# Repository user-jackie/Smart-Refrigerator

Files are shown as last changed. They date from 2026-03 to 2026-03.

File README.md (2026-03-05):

# Smart-Refrigerator
A smart refrigerator based on rk3568

如果学习过相关内容的同学就会发现这个东西是基本没有技术难度的，那为什么要做这个东西呢，因为是学校的课，懂得都懂。虽然没有技术难度，但毕竟是本人第一个伪全栈项目(因为rk3568的高速板用的是开发板)，还是比较有纪念意义的。

说一下感想吧，现在ai的发展真是日新月异。如果让我从头写这些qt代码可能一个月都写不出来，但是现在用ai来写一个星期功能就大差不差，还是用的免费的Claude Code版本。个人感觉学习技术的成本越来越低，特别是和应用型代码相关的技术，也许以后使用一门技术只需要了解这门技术叫什么名字就行了？遵循规则是没有出路的，要么制定规则，要么打破规则。

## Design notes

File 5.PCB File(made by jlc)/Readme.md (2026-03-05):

# 嘉立创PCB文件

这里的pcb主要是两个扩展板，使用的开发板不一样的话pcb文件没有参考价值，不建议下载，这里给出思路。

1.因为做的是一个民用产品，所以首先得需要220v的电压输入转为直流输出，在淘宝上买一个220v转12v的变压器(转多少v直流自己决定)，转12v是因为提前买了12v的加热片和制冷片。

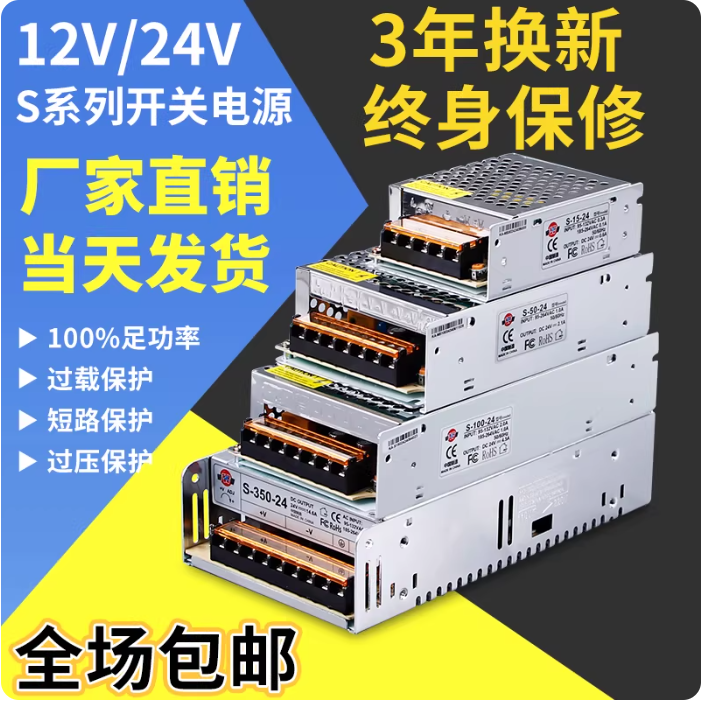
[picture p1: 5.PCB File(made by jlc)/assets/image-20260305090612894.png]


2.因为需要使用开发板上的gpio控制外部器件的通断，rk3568 gpio最高输出3.3v，所以需要一个能够3.3v控制12v电压通断的元件，作者选用的是3.3v电平触发的继电器(需要考虑到12v那边的最大电流，大功率制冷片需要的电流很大)，理论上来说也可以三极管或者mos管，但三极管需要拉高基极电压，mos管需要拉高栅极电压，我在设计时考虑的是都得拉高到12v左右才能控制通断，但gpio只能输出3.3v电压，我也想过手动拉高，但可能会导致电流倒流？现在想想好像可以拉低发射极或者漏极电压？各位如果会使用的话可以尝试使用这种能通过大电流的相关器件，好处是可以使用pwm波来动态控制制冷片和加热片的电流，坏处呢，好像基本没有坏处。

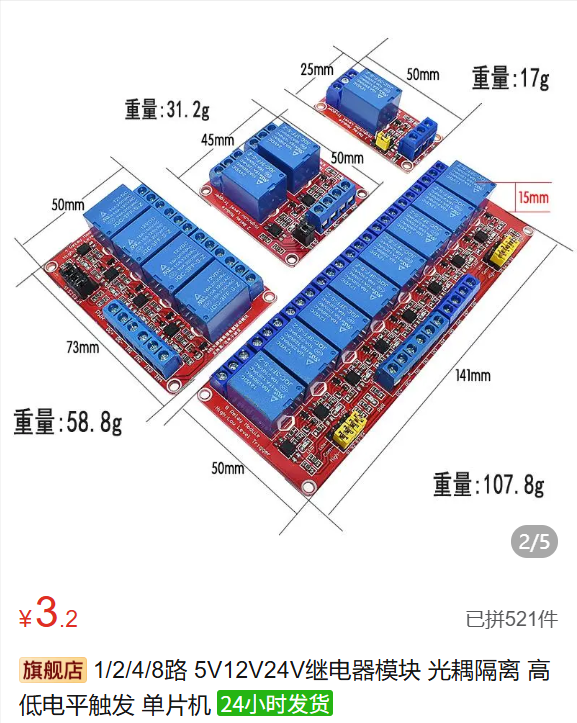
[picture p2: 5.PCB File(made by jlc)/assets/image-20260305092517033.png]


3.冰箱内部的温度获取使用ds18b20，驱动代码和设备树配置在`4.Driver Code`文件夹中，这种单总线协议用软件模拟的时序，所以移植起来还是比较简单，驱动代码不用改，设备树的配置根据自己使用的芯片和引脚进行配置。

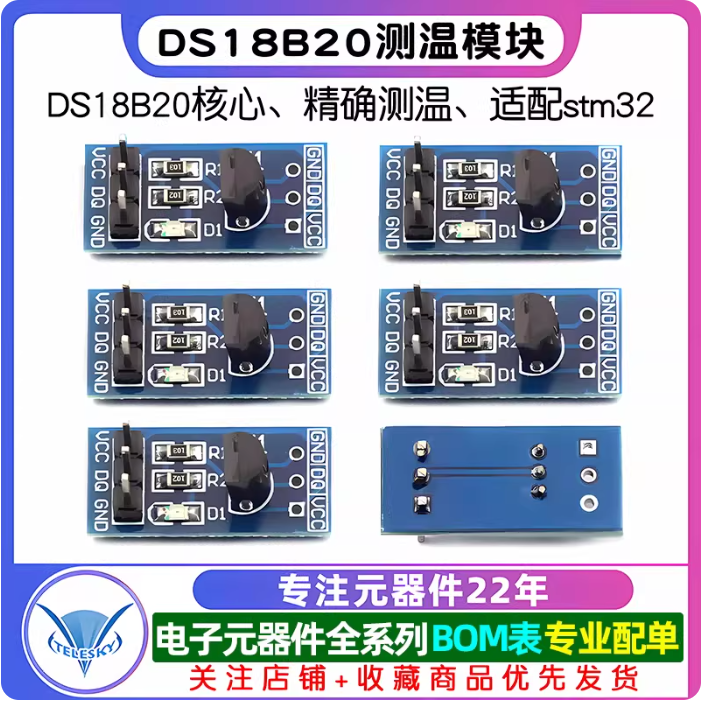
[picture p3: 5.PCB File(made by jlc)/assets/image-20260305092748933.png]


4.工作电压为12V功率为51W半导体制冷片(功率需要慎重选择，一个是因为功率越大需要的散热量更多，另一个是功率越大需要的电流越大，可能继电器不支持)。

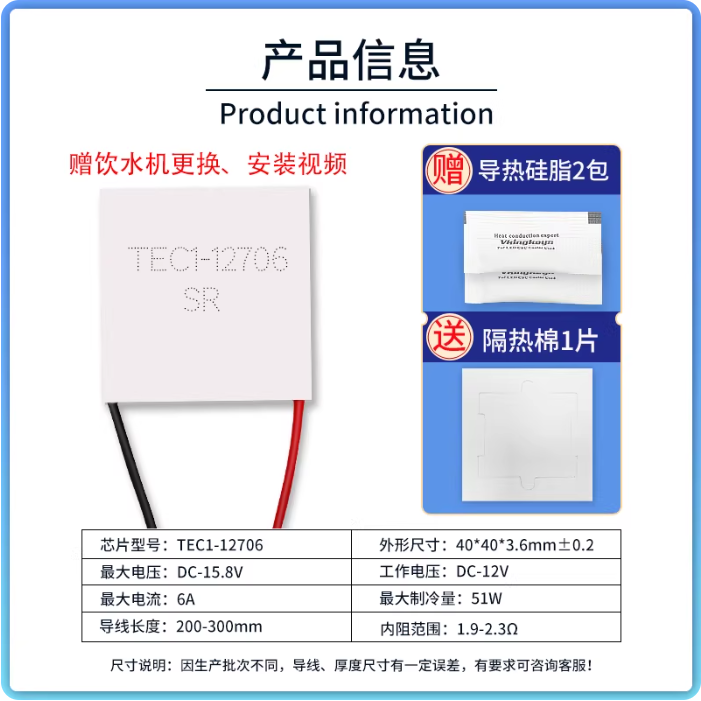
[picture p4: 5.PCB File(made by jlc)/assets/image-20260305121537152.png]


5.工作电压为12V的PTC智能加热片，60度恒温发热，一个功率十几瓦(这个功率也要慎重选择，防止继电器损坏)

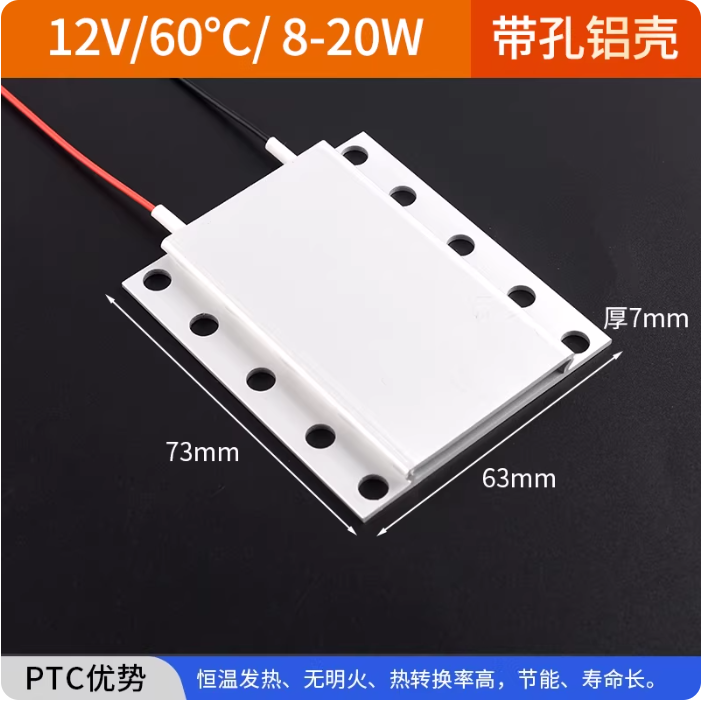
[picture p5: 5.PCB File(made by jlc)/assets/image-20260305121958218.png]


6.用于照明的白色led灯，用于杀菌的紫外线led灯，用于空气净化的风扇加滤芯基本上除了电压没有什么要求，因为电流都不大，一般的继电器完全够用。

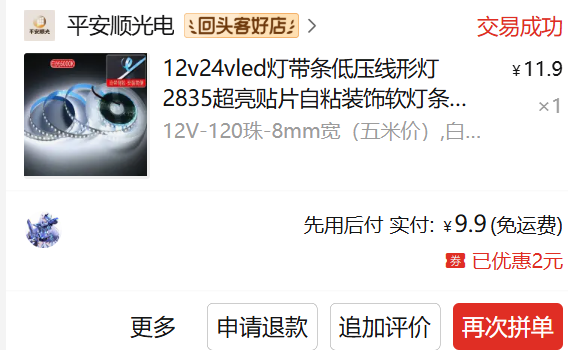
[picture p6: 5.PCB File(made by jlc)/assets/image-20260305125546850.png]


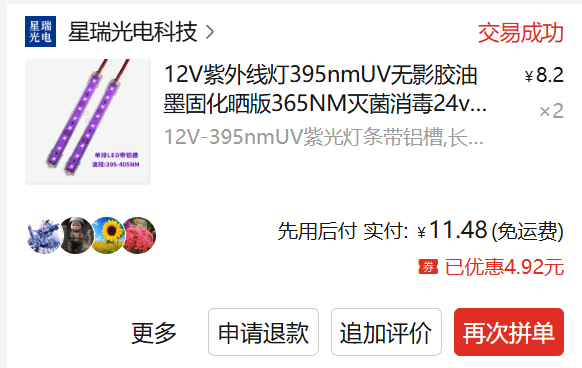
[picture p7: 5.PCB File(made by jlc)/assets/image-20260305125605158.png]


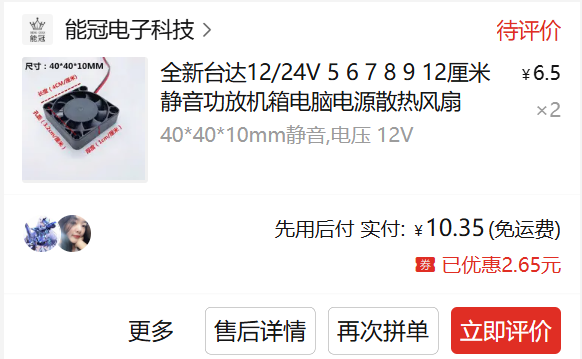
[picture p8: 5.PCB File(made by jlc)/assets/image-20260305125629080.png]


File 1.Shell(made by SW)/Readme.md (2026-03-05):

# 冰箱外壳

文件分为装配体文件和用于打印的文件

1.装配体文件

`装配体.SLDASM`文件是冰箱外壳的总文件。

2.打印文件在名字叫`打印文件`的文件夹中，都是.stl类型文件，由于使用的是自己的打印机，每条边长度不能超过20cm，所以有些模块进行了分段打印，如果自己打印机比较大或者给在淘宝上打印可以不用使用这种文件。

3.冰箱外壳预览

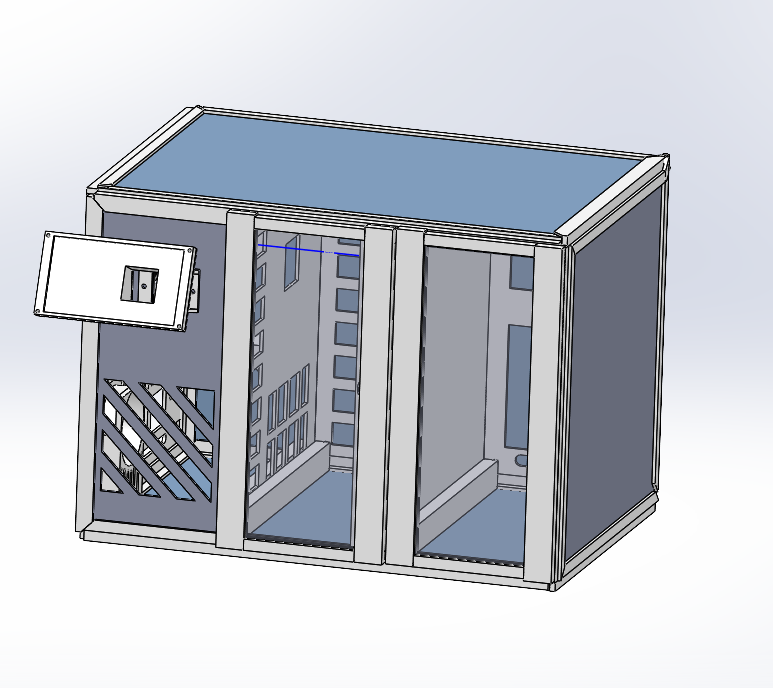
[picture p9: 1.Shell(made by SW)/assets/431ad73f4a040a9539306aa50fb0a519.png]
431ad73f4a040a9539306aa50fb0a519


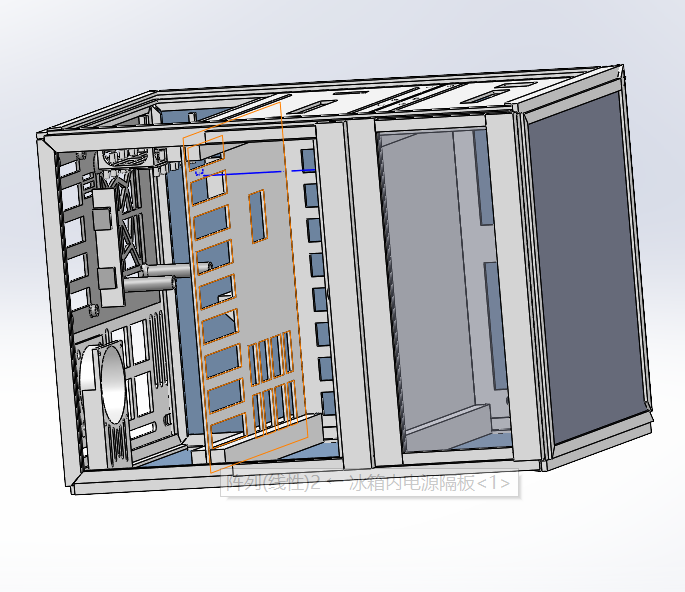
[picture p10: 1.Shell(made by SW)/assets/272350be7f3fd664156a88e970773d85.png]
272350be7f3fd664156a88e970773d85


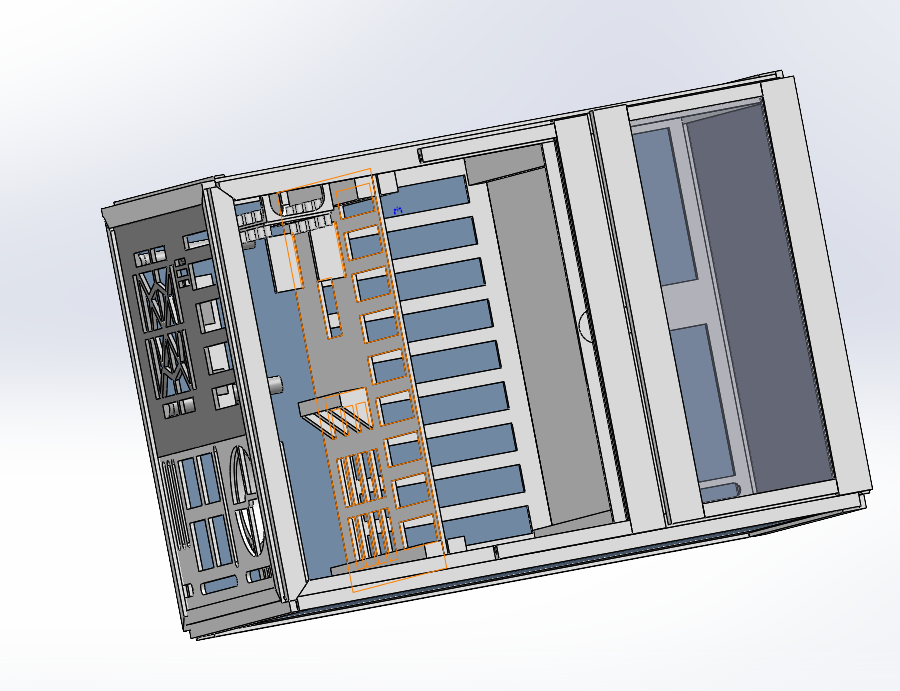
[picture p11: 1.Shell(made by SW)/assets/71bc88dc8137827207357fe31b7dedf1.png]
71bc88dc8137827207357fe31b7dedf1


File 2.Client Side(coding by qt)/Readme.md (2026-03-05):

# QT前端代码

qt版本信息，不同版本需要考虑兼容性的问题，可以在网上搜索教程

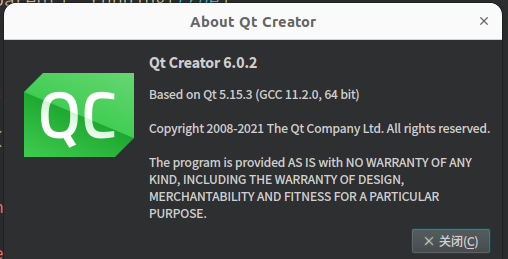
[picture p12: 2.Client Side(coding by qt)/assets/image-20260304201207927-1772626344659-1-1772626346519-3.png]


代码就如文件夹内所示，将文件导入到ubuntu虚拟机后在qt里面打开.pro文件即可，只要是设计了5个页面

1. 温度控制：使用ds18b20获取环境温度，在页面上设计加热和制冷的分页图标，温度控制可以使用上下拖动模式，也可以点击温度手动设置。
2. ai对话：微信聊天形式的页面显示。
3. 环境状态获取：显示当前位置的温湿度、pm2.5浓度等，同时可以获取近两小时的下雨状况。
4. 紫外线杀菌和空气净化：同样使用分页图标，点击时间可以手动设置时间，时间结束后自动停止。
5. wifi连接：扫描周围wifi，然后可以手动输入密码进行连接，如果不连接wifi的话ai对话和环境状态无法获取。

不想继续进行文件修改的读者可以在开发板上配置好qt5环境后直接执行`bingxiang_demo_output`文件夹内的[bingxiang_demo](./bingxiang_demo_output/bingxiang_demo)即可。

作者知道使用像rk3568这种高速开发板进行前后端代码设计，不将开发板的原理图和pcb板文件给出，单移植代码复刻起来难度比较高(可能作者比较菜，但前几天看高速板设计真是看着头大，所以放弃了学习高速板的想法)，所以这里给出作者写qt代码时遇到的问题，希望对各位有帮助。

1.搭建qt交叉编译环境问题

在说问题之前先给不知道的读者科普一下，qt交叉编译环境的搭建需要gcc/g++、qmake、qtcreator这三样东西，qtcreator就是下载的软件，qmake和gcc/g++需要自己手动下载(因为ubuntu或者windows上下载的qt自带gcc/g++和qmake都是服务x86架构的，而开发板一般是arm架构)，根据自己的开发板，一般厂商都会给出qmake和gcc/g++的文件，直接配置即可。

我遇到的问题主要是32位arm的qmake不能兼容64位arm的qmake，这个问题看起来很蠢，但是由于作者之前学习过i.mx6ull开发板的配置，那个时候下载过一次qmake，但是是32位的，想偷个懒就没按3568厂商给的教程重新下载，直到作者发现原来将鼠标移动到报错位置可以查看报错信息...

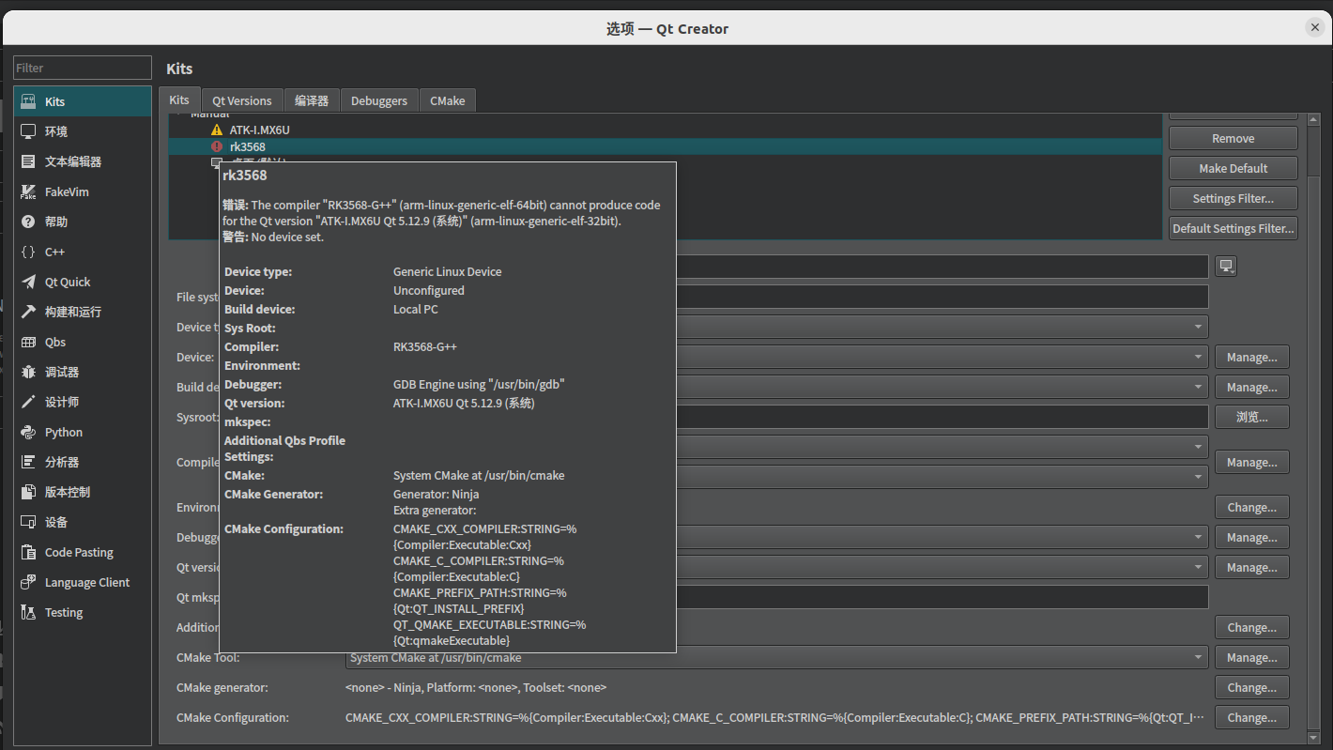
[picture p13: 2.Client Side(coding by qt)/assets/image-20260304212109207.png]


2.qt部署远程连接设备问题

主要是不知道ssh连接相关的内容，导致使用default模式每次都要手动输入密码，比较麻烦，后面查了一下公私钥的定义，使用Specific_key模式就解决了。

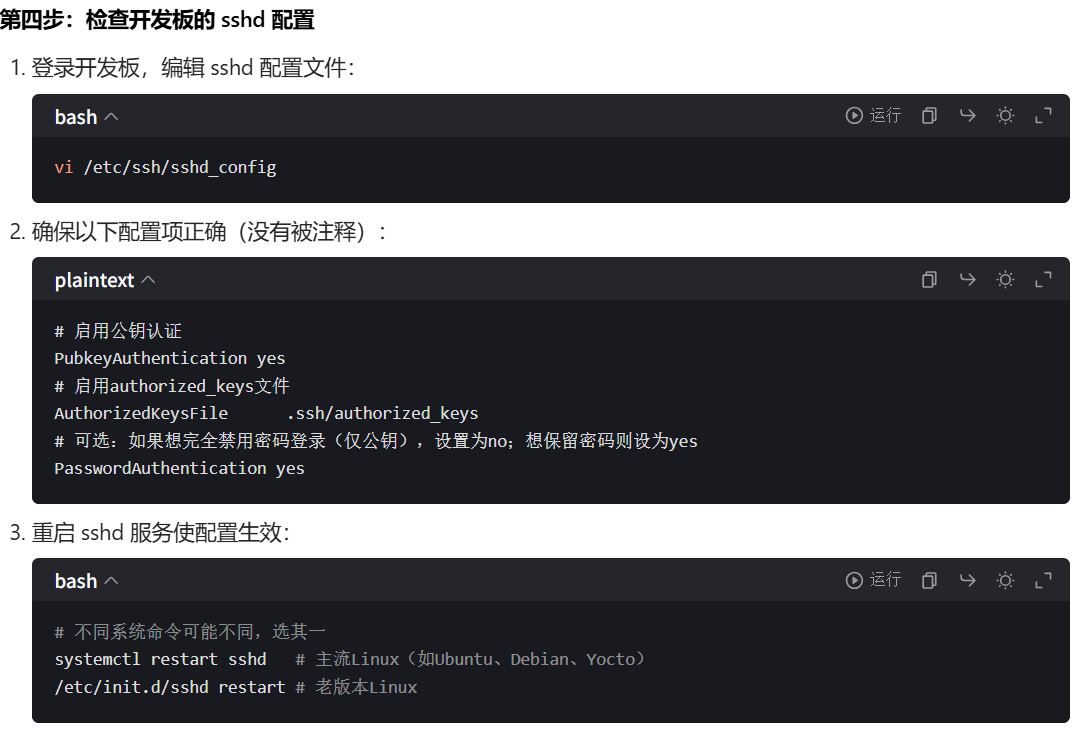
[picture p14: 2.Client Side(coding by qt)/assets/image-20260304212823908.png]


配置好后在qt里面创建密钥，然后将密钥部署到开发板

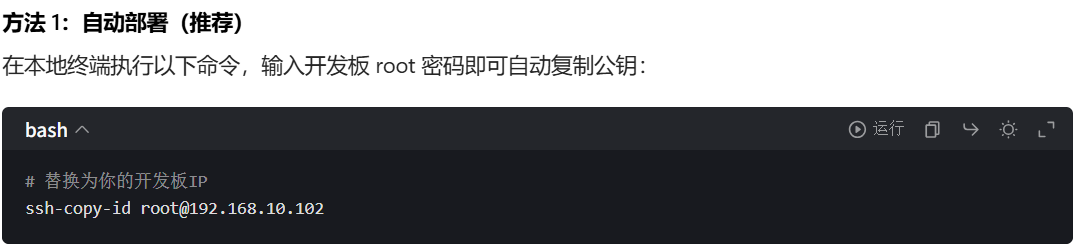
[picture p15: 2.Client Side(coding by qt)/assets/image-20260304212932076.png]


上面都是询问豆包得到的解决方法，不得不说现在ai还是很强大的。

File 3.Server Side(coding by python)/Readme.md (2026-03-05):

# Python后端代码

接入了阿里云百炼的ASR(自动语音识别)、LLM(大语言模型)、TTS(文本转语音)这3种技术的api，能实现语音助手的功能。

接入了和风天气的api，能够查询某个地区的天气信息

后端代码的使用没有任何限制，只需要搭建好python环境即可使用，一般执行文件时报错`from xxx import aaa`，这种一般使用`pip install xxx`命令下载xxx库即可，但是有些库可能变了名字，导致下载的时候找不到！此代码中库有一个是变了名字的，这种缺库的问题推荐是现在浏览器上找答案，找不到再问ai(你敢问ai真敢忽悠)。

下载好库后直接使用python命令执行代码即可

注意：

1.和风天气的后端代码在什么时间启动都可以，但是阿里云百炼的api必须在前端qt代码启动前启动，写启动脚本的时候需要留意一下顺序。

2.阿里云的需要使用个人的api-key，和风天气需要使用个人的api-key和api-host，创建账号之后再创建工程即可。

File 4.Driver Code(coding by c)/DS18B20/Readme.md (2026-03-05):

# 设备树配置

1.rk3568-pinctrl.dtsi（芯片级引脚复用配置文件）

`ds18b20 {`

    `ds18b20_gpio: ds18b20-gpio {`

      `rockchip,pins = <3 RK_PB6 RK_FUNC_GPIO &pcfg_pull_up>; /* 用于设置引脚的电气属性 */`

    `};`

  `};`

2.rk3568-xxxx.dtsi/.dts（开发板定制化设备树文件，根据开发板不同命名不同）

`ds18b20@0 {`

    `compatible = "rockchip,rk3568-ds18b20";  */\* 与驱动的compatible严格匹配 \*/*`

    `status = "okay";             */\* 使能节点 \*/*`

    `ds18b20-gpios = <&gpio3 RK_PB6 GPIO_ACTIVE_HIGH>; */\* GPIO3B6，高电平有效 \*/*`

    `pinctrl-names = "default";`

    `pinctrl-0 = <&ds18b20_gpio>;       */\* 引脚复用配置 \*/*`

  `};`

二者的关系为

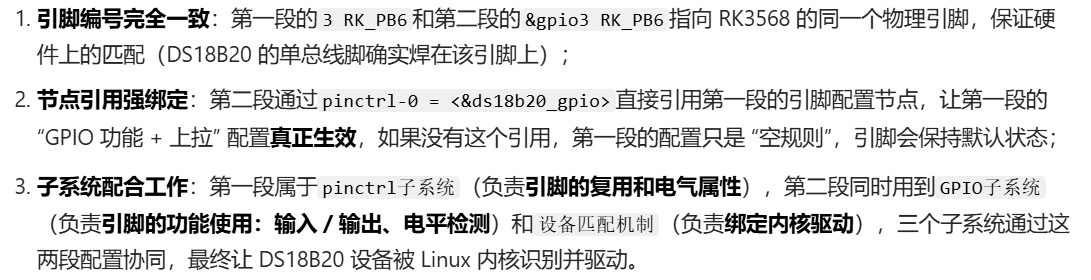
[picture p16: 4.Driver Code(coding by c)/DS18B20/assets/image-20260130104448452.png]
relation1


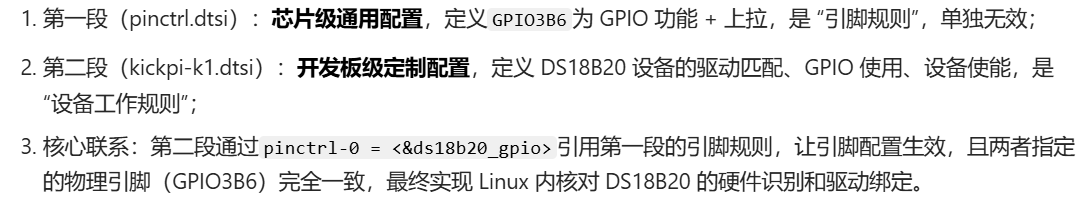
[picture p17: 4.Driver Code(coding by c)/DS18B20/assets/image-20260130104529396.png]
relation2


3.Makefile文件中

`KERNELDIR := /home/brojackie/RK3568/rk356x-linux/rk356x-linux/kernel`

和

`CROSS_COMPILE ?= /home/brojackie/RK3568/rk356x-linux/rk356x-linux/prebuilts/gcc/linux-x86/aarch64/gcc-arm-10.3-2021.07-x86_64-aarch64-none-linux-gnu/bin/aarch64-none-linux-gnu-`

根据个人的文件文件位置进行更改

更改完成后使用`make`指令并将编译出的`ds18b20_driver.ko`文件和`ds18b20_App`文件导入开发板的`/lib/modules/5.10.160`(根据自己开发板选择)，然后使用`depmod`命令加载模块依赖，使用`modprobe ds18b20_driver.ko` 加载模块，使用`./ds18b20_App`指令执行app文件，就可以开始读取温度。

正常工作时

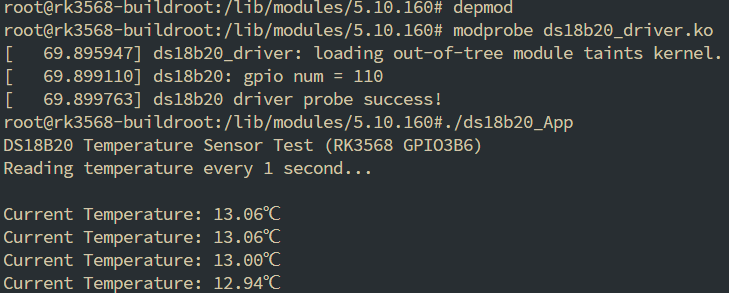
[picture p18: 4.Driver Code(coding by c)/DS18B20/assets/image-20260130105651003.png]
running


如果报错优先检查设备树上引脚是不是被占用，其他情况根据具体报错内容修改，驱动文件应该没有问题。

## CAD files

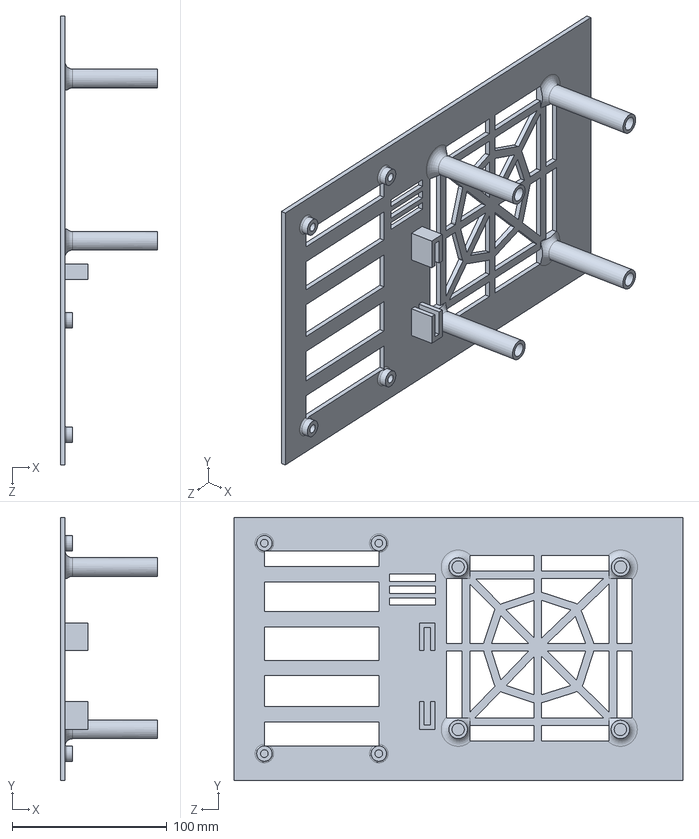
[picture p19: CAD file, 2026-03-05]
1.Shell(made by SW)/冰箱零件和装配体/冰箱侧2上.SLDPRT
63.0 x 170.0 x 290.0 mm

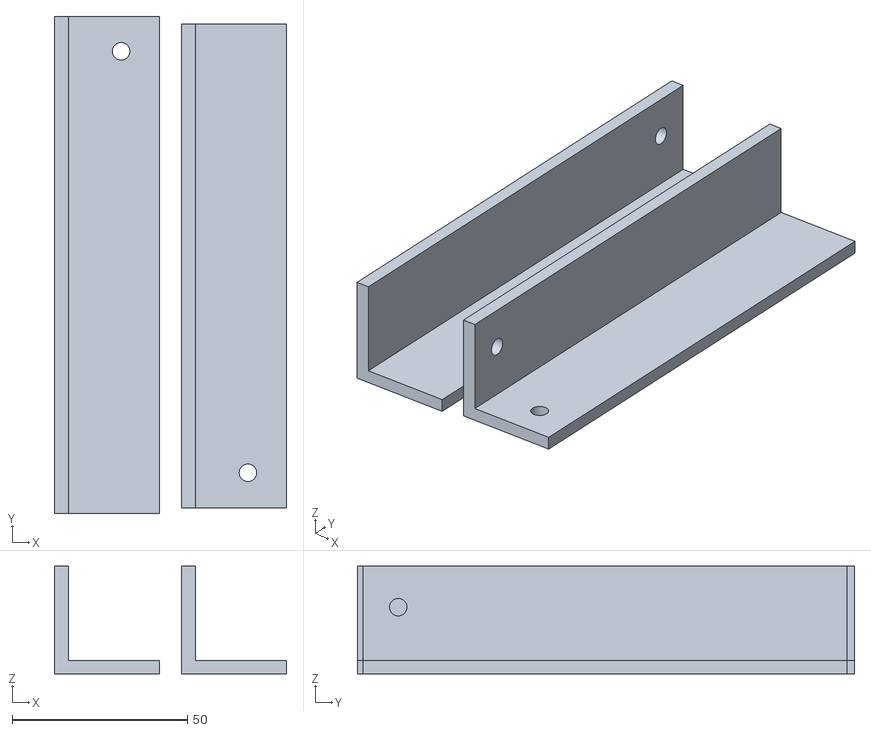
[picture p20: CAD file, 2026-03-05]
1.Shell(made by SW)/打印文件/侧连接.stl
66.2 x 141.9 x 30.7

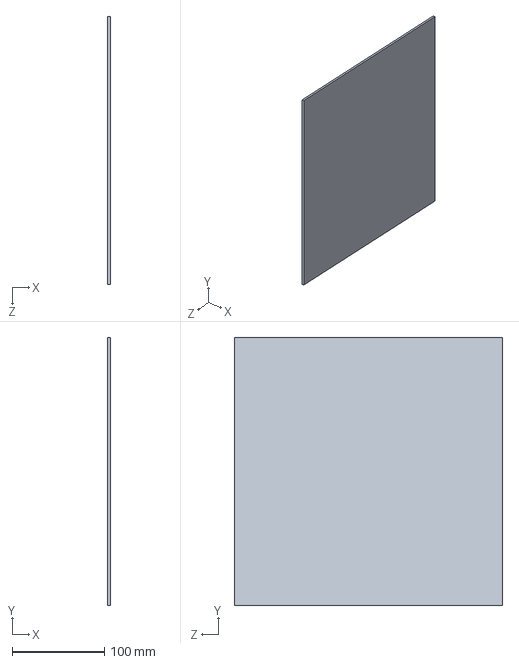
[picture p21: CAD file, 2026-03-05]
1.Shell(made by SW)/冰箱零件和装配体/冰箱侧1.SLDPRT
3.00 x 290.0 x 290.0 mm

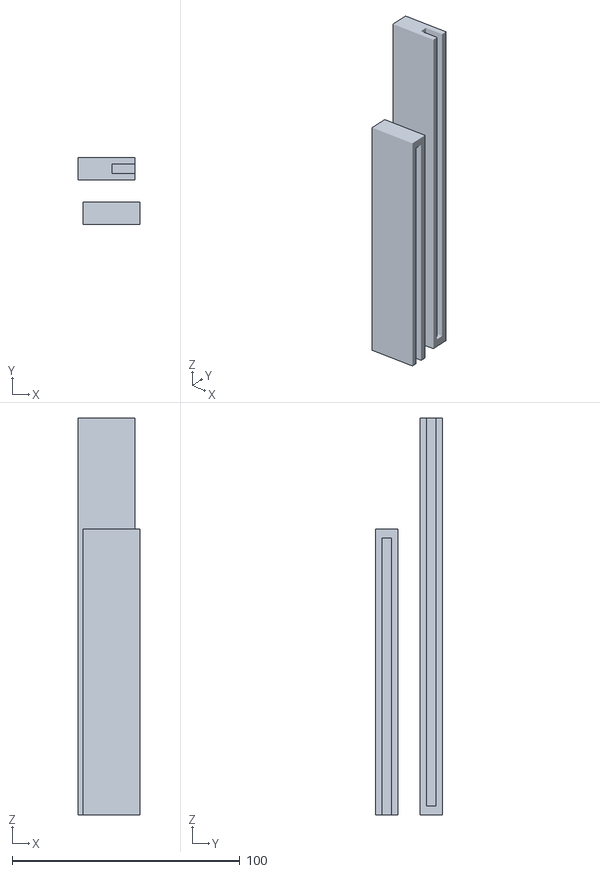
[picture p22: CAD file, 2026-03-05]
1.Shell(made by SW)/打印文件/冰箱门.STL
27.4 x 29.6 x 174.4

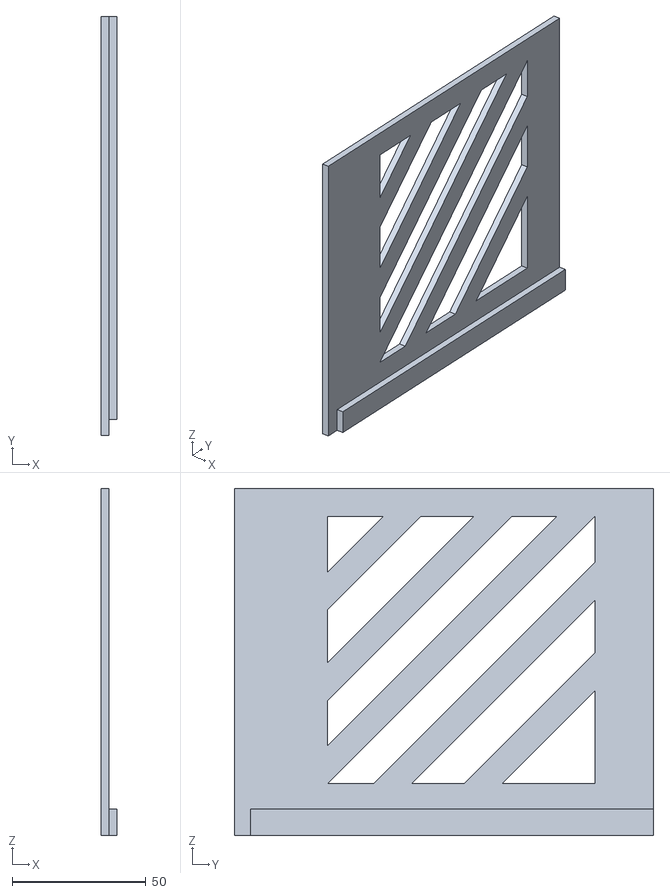
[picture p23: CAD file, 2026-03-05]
1.Shell(made by SW)/打印文件/冰箱电源门002.stl
6.00 x 156.9 x 130.0

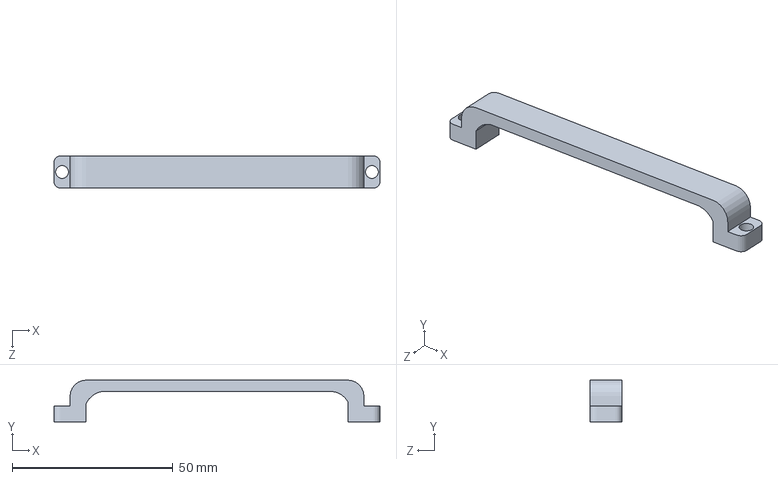
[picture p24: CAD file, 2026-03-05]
1.Shell(made by SW)/冰箱零件和装配体/把手.SLDPRT
101.5 x 13.0 x 10.0 mm

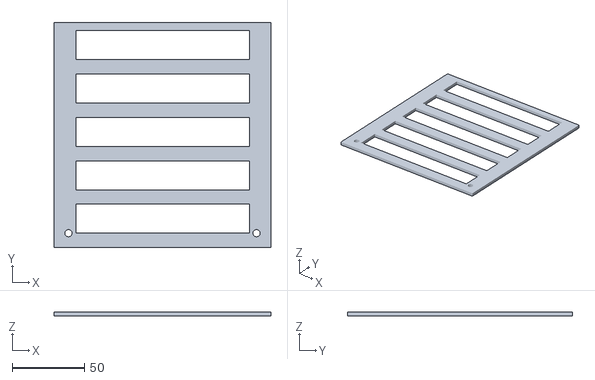
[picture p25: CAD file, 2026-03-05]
1.Shell(made by SW)/打印文件/内胆冷侧001.stl
150.0 x 155.7 x 3.00

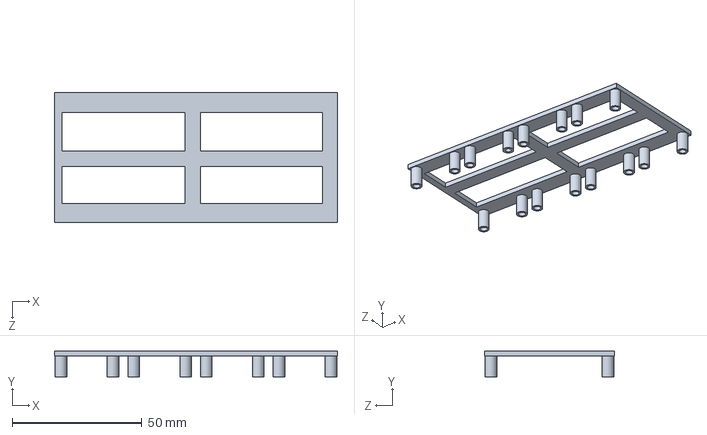
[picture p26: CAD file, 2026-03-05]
1.Shell(made by SW)/冰箱零件和装配体/继电器壳.SLDPRT
109.0 x 10.0 x 50.0 mm

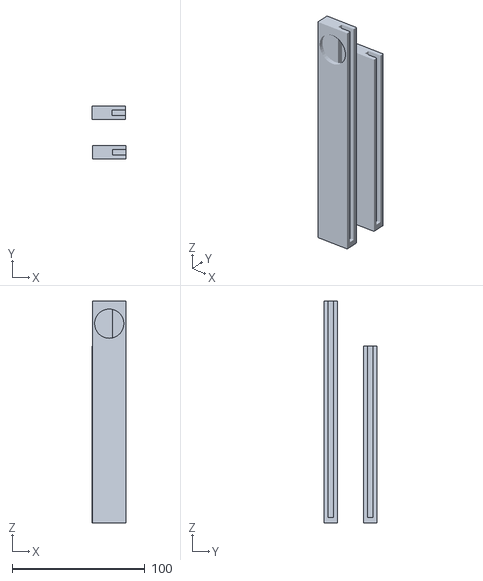
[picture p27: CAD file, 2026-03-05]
1.Shell(made by SW)/打印文件/冰箱门磁吸侧.STL
25.4 x 39.6 x 167.0

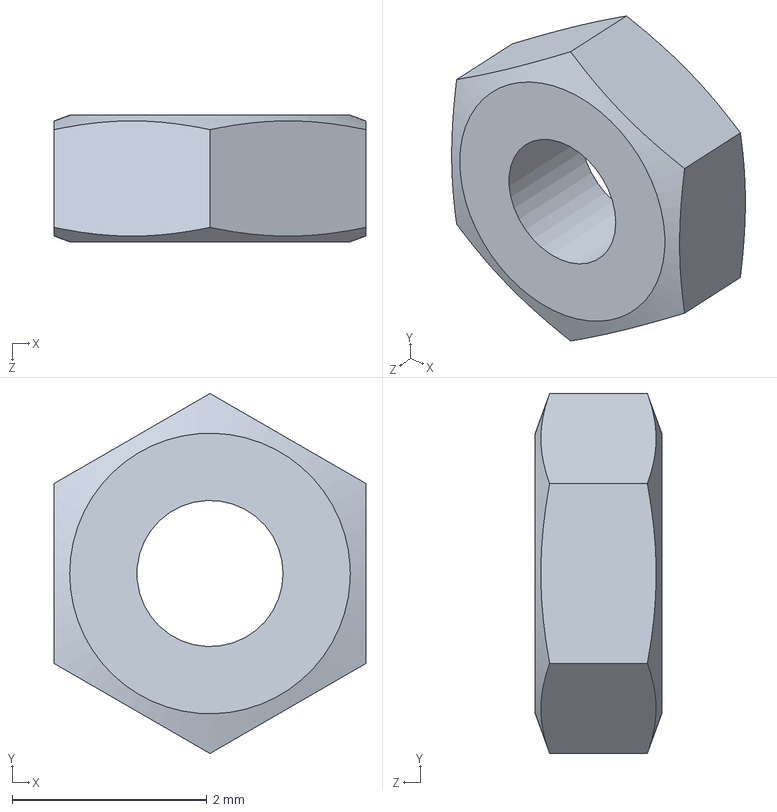
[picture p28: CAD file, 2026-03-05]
1.Shell(made by SW)/冰箱零件和装配体/六角螺母 M6.SLDPRT
3.20 x 3.70 x 1.30 mm

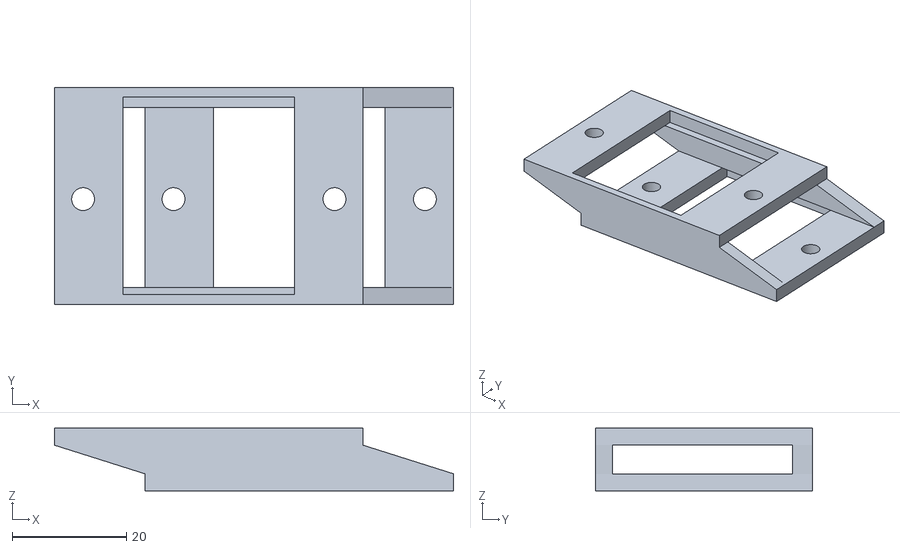
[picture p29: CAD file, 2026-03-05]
1.Shell(made by SW)/打印文件/屏幕连接.STL
69.8 x 38.0 x 11.0

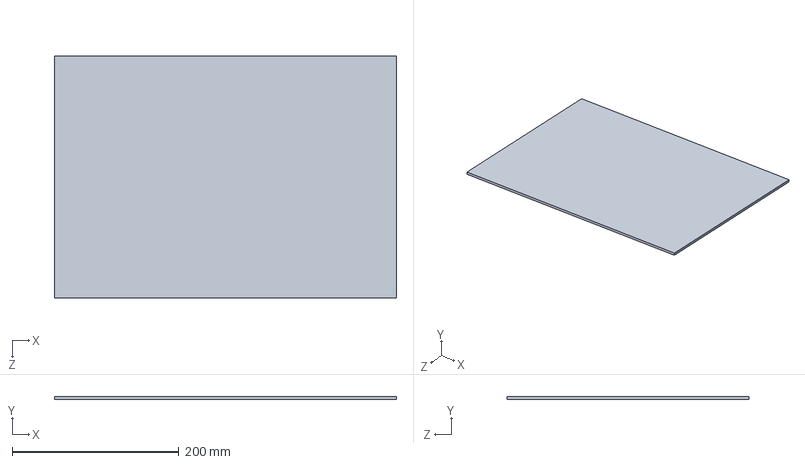
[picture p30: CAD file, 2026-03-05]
1.Shell(made by SW)/冰箱零件和装配体/冰箱顶.SLDPRT
410.0 x 4.00 x 290.0 mm

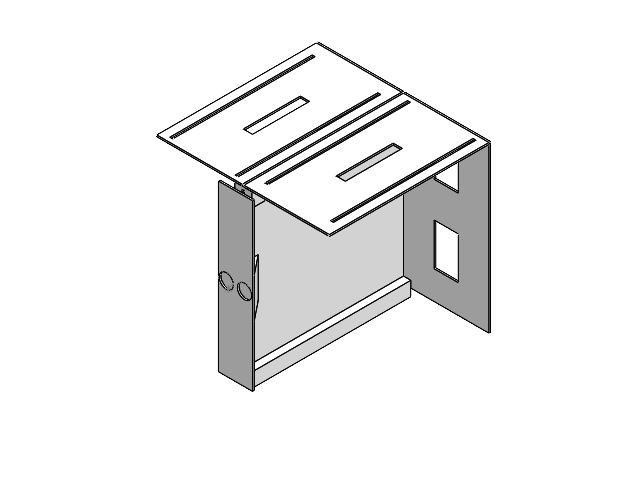
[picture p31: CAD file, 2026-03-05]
1.Shell(made by SW)/冰箱零件和装配体/内胆装配体.SLDASM
内胆卡槽 x 2
冰箱内冷热隔板
内胆顶 x 2
内胆热侧
内胆冷侧
内胆门吸

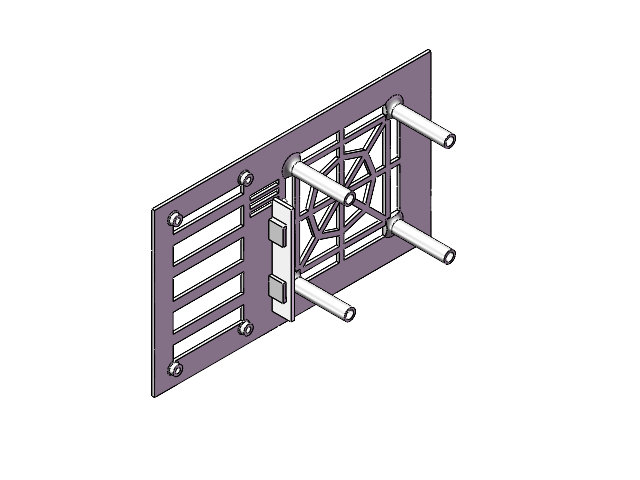
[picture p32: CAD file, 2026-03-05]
1.Shell(made by SW)/冰箱零件和装配体/冰箱侧2上装配体.SLDASM
冰箱侧2上
PCB支撑

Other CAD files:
1.Shell(made by SW)/冰箱零件和装配体/继电器装配体.SLDASM
1.Shell(made by SW)/冰箱零件和装配体/装配体.SLDASM
1.Shell(made by SW)/冰箱零件和装配体/电源隔板装配体.SLDASM
1.Shell(made by SW)/冰箱零件和装配体/屏幕装配体.SLDASM
1.Shell(made by SW)/冰箱零件和装配体/PCB支撑.SLDPRT
1.Shell(made by SW)/冰箱零件和装配体/Refri True TBB 24 48G S HC LD.SLDPRT
1.Shell(made by SW)/冰箱零件和装配体/侧连接.SLDPRT
1.Shell(made by SW)/冰箱零件和装配体/六角螺栓 M6x10.SLDPRT
1.Shell(made by SW)/冰箱零件和装配体/六角螺栓 M6x5.SLDPRT
1.Shell(made by SW)/冰箱零件和装配体/内胆冷侧.SLDPRT
1.Shell(made by SW)/冰箱零件和装配体/内胆卡槽.SLDPRT
1.Shell(made by SW)/冰箱零件和装配体/内胆热侧.SLDPRT
1.Shell(made by SW)/冰箱零件和装配体/内胆门吸.SLDPRT
1.Shell(made by SW)/冰箱零件和装配体/内胆顶.SLDPRT
1.Shell(made by SW)/冰箱零件和装配体/冰箱.SLDPRT
1.Shell(made by SW)/冰箱零件和装配体/冰箱侧2下.SLDPRT
1.Shell(made by SW)/冰箱零件和装配体/冰箱内冷热隔板.SLDPRT
1.Shell(made by SW)/冰箱零件和装配体/冰箱内电源隔板.SLDPRT
1.Shell(made by SW)/冰箱零件和装配体/冰箱电源门.SLDPRT
1.Shell(made by SW)/冰箱零件和装配体/冰箱门.SLDPRT
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

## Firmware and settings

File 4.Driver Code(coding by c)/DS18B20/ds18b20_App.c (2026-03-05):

#include "ds18b20_App.h"

// 读取指定传感器温度
int ds18b20_read_temperature(const char *dev_path, char *temp_buf, int buf_size)
{
    int fd;
    int ret;
    char raw_buf[TEMP_BUF_SIZE];
    int temp_raw;
    float temp_real;

    // 打开指定设备节点
    fd = open(dev_path, O_RDONLY);
    if (fd < 0) {
        perror("open ds18b20 device failed");
        return -1;
    }

    // 清空缓冲区
    memset(raw_buf, 0, sizeof(raw_buf));
    memset(temp_buf, 0, buf_size);

    // 读取原始温度数据
    ret = read(fd, raw_buf, sizeof(raw_buf) - 1);
    if (ret < 0) {
        perror("read ds18b20 raw data failed");
        close(fd);
        return -1;
    }
    close(fd);

    // 字符串转整数，换算实际温度
    temp_raw = atoi(raw_buf);
    temp_real = temp_raw * 0.0625f; // DS18B20官方换算公式
    snprintf(temp_buf, buf_size, "%.2f℃", temp_real);

    return 0;
}

// 主函数：同时读取两个传感器温度
int main(int argc, char *argv[])
{
    char temp_buf0[TEMP_BUF_SIZE];
    char temp_buf1[TEMP_BUF_SIZE];
    int ret0, ret1;

    printf("DS18B20 Double Sensor Test (RK3568)\n");
    printf("Sensor0(GPIO4C4)  Sensor1(GPIO3B5)\n");
    printf("----------------------------------\n");

    while (1) {
        // 读取传感器0温度
        ret0 = ds18b20_read_temperature(DS18B20_DEV_PATH_0, temp_buf0, TEMP_BUF_SIZE);
        // 读取传感器1温度
        ret1 = ds18b20_read_temperature(DS18B20_DEV_PATH_1, temp_buf1, TEMP_BUF_SIZE);

        // 输出温度
        if (ret0 == 0 || ret1 == 0) {
            printf("\rSensor0(GPIO4C4): %-10s  Sensor1(GPIO3B5): %-10s", temp_buf0, temp_buf1);
        } else {
            printf("\rSensor0(GPIO4C4): 读取失败  Sensor1(GPIO3B5): 未连接/读取失败");
        }
        fflush(stdout);

        sleep(1);
    }

    return 0;
}

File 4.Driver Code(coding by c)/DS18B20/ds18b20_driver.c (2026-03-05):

#include <linux/types.h>
#include <linux/kernel.h>
#include <linux/delay.h>
#include <linux/ide.h>
#include <linux/init.h>
#include <linux/module.h>
#include <linux/errno.h>
#include <linux/gpio.h>
#include <linux/cdev.h>
#include <linux/device.h>
#include <linux/of.h>
#include <linux/of_address.h>
#include <linux/of_gpio.h>
#include <asm/uaccess.h>
#include <asm/io.h>
#include <linux/semaphore.h>
#include <linux/timer.h>
#include <linux/irq.h>
#include <linux/wait.h>
#include <linux/poll.h>
#include <linux/fs.h>
#include <linux/fcntl.h>
#include <linux/platform_device.h>

#define DS18B20_NAME "ds18b20"
#define DS18B20_CNT  2          // 设备数量改为2

// 设备结构体（支持多设备，增加index标识）
struct ds18b20_dev {
    dev_t devid;              // 字符设备号
    struct cdev cdev;         // 字符设备
    struct class *class;      // 设备类（全局共享）
    struct device *device;    // 设备节点（每个设备独立）
    struct device *dev;       // 平台设备
    int major;                // 主设备号
    int minor;                // 次设备号
    int ds18b20_gpio;         // 对应GPIO编号
    struct device_node *nd;   // 设备节点
    int index;                // 设备索引（0/1）
};
static struct ds18b20_dev ds18b20_dev[DS18B20_CNT]; // 设备数组
static struct class *ds18b20_class;                 // 全局设备类

/********************* DS18B20单总线核心时序（适配多设备）*********************/
// 设置GPIO为输出模式（绑定具体设备）
static void ds18b20_gpio_output(struct ds18b20_dev *dev)
{
    gpio_direction_output(dev->ds18b20_gpio, 1);
}

// 设置GPIO为输入模式（绑定具体设备）
static void ds18b20_gpio_input(struct ds18b20_dev *dev)
{
    gpio_direction_input(dev->ds18b20_gpio);
}

// 设置数据口电平（绑定具体设备）
static void ds18b20_set_gpio(struct ds18b20_dev *dev, int val)
{
    gpio_set_value(dev->ds18b20_gpio, val);
}

// 读取数据口电平（绑定具体设备）
static int ds18b20_get_gpio(struct ds18b20_dev *dev)
{
    return gpio_get_value(dev->ds18b20_gpio);
}

// DS18B20复位（适配多设备）
static int ds18b20_reset(struct ds18b20_dev *dev)
{
    int ret;
    // 1. 主机拉低总线480~960us
    ds18b20_gpio_output(dev);
    ds18b20_set_gpio(dev, 0);
    udelay(600);
    // 2. 主机释放总线，等待15~60us
    ds18b20_set_gpio(dev, 1);
    ds18b20_gpio_input(dev);
    udelay(80);
    // 3. 检测从机应答（拉低总线60~240us）
    ret = ds18b20_get_gpio(dev);
    // 4. 等待总线释放
    udelay(500);
    return ret; // 0:复位成功，1:失败
}

// 单总线读1bit（适配多设备）
static u8 ds18b20_read_bit(struct ds18b20_dev *dev)
{
    u8 bit = 0;
    // 主机拉低总线至少1us
    ds18b20_gpio_output(dev);
    ds18b20_set_gpio(dev, 0);
    udelay(2);
    // 主机释放总线
    ds18b20_set_gpio(dev, 1);
    ds18b20_gpio_input(dev);
    udelay(10);
    // 读取总线电平
    if (ds18b20_get_gpio(dev))
        bit = 1;
    else
        bit = 0;
    // 等待时序完成（至少45us）
    udelay(50);
    return bit;
}

// 单总线读1字节（适配多设备）
static u8 ds18b20_read_byte(struct ds18b20_dev *dev)
{
    u8 i, byte = 0;
    for (i = 0; i < 8; i++) {
        byte >>= 1;
        if (ds18b20_read_bit(dev))
            byte |= 0x80;
    }
    return byte;
}

// 单总线写1字节（适配多设备）
static void ds18b20_write_byte(struct ds18b20_dev *dev, u8 byte)
{
    u8 i, bit;
    ds18b20_gpio_output(dev);
    for (i = 0; i < 8; i++) {
        bit = byte & 0x01;
        byte >>= 1;
        // 写0：拉低总线60~120us
        if (bit == 0) {
            ds18b20_set_gpio(dev, 0);
            udelay(80);
            ds18b20_set_gpio(dev, 1);
            udelay(2);
        } else { // 写1：拉低总线1~15us，然后释放
            ds18b20_set_gpio(dev, 0);
            udelay(2);
            ds18b20_set_gpio(dev, 1);
            udelay(80);
        }
    }
}

/********************* DS18B20温度读取（适配多设备）*********************/
static int ds18b20_read_temp(struct ds18b20_dev *dev, int *temp_raw)
{
    u8 temp_h, temp_l;
    u16 temp_val;
    // 1. 复位DS18B20，失败直接返回
    if (ds18b20_reset(dev) != 0) {
        printk("DS18B20_%d reset failed!\n", dev->index);
        return -EIO;
    }
    // 2. 跳过ROM（单设备挂载专用）
    ds18b20_write_byte(dev, 0xCC);
    // 3. 发送温度转换命令，等待转换完成
    ds18b20_write_byte(dev, 0x44);
    mdelay(750);
    // 4. 再次复位，准备读取原始数据
    if (ds18b20_reset(dev) != 0) {
        printk("DS18B20_%d reset failed!\n", dev->index);
        return -EIO;
    }
    // 5. 跳过ROM，发送读数据命令
    ds18b20_write_byte(dev, 0xCC);
    ds18b20_write_byte(dev, 0xBE);
    // 6. 读取原始温度数据
    temp_l = ds18b20_read_byte(dev);
    temp_h = ds18b20_read_byte(dev);
    temp_val = (temp_h << 8) | temp_l;
    // 7. 传递原始16位整数
    *temp_raw = (int)temp_val;
    return 0;
}

/********************* 字符设备操作接口（适配多设备）*********************/
static int ds18b20_open(struct inode *inode, struct file *filp)
{
    int minor = iminor(inode);          // 获取次设备号
    filp->private_data = &ds18b20_dev[minor]; // 绑定设备结构体
    return 0;
}

static ssize_t ds18b20_read(struct file *filp, char __user *buf, size_t size, loff_t *ppos)
{
    struct ds18b20_dev *dev = filp->private_data; // 获取当前设备
    int temp_raw;
    char temp_buf[32];
    int ret;

    // 读取对应传感器的原始温度
    ret = ds18b20_read_temp(dev, &temp_raw);
    if (ret < 0)
        return ret;

    // 格式化原始整数字符串
    snprintf(temp_buf, sizeof(temp_buf), "%d\n", temp_raw);
    // 拷贝到用户空间
    ret = copy_to_user(buf, temp_buf, strlen(temp_buf));
    if (ret < 0) {
        printk("copy to user failed for ds18b20_%d!\n", dev->index);
        return -EFAULT;
    }
    // 防止重复读取
    if (*ppos > 0)
        return 0;
    *ppos += strlen(temp_buf);
    return strlen(temp_buf);
}

static int ds18b20_release(struct inode *inode, struct file *filp)
{
    return 0;
}

// 字符设备操作集
static const struct file_operations ds18b20_fops = {
    .owner = THIS_MODULE,
    .open = ds18b20_open,
    .read = ds18b20_read,
    .release = ds18b20_release,
};

/* 初始化单个DS18B20的GPIO */
static int ds18b20_gpio_init(struct ds18b20_dev *dev, struct device_node *nd)
{
    int ret;

    /* 从设备树读取GPIO属性 */
    dev->ds18b20_gpio = of_get_named_gpio(nd, "ds18b20-gpios", 0);
    if (dev->ds18b20_gpio < 0) {
        pr_err("ds18b20_%d: can't get gpio from DT\n", dev->index);
        return -EINVAL;
    }
    pr_info("ds18b20_%d: gpio num = %d\n", dev->index, dev->ds18b20_gpio);

    /* 请求并配置GPIO */
    ret = gpio_request(dev->ds18b20_gpio, "ds18b20");
    if (ret) {
        pr_err("ds18b20_%d: gpio_request failed, ret=%d\n", dev->index, ret);
        return ret;
    }
    ret = gpio_direction_output(dev->ds18b20_gpio, 1);
    if (ret) {
        pr_err("ds18b20_%d: gpio_direction_output failed\n", dev->index);
        gpio_free(dev->ds18b20_gpio);
        return -EINVAL;
    }

    return 0;
}
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
